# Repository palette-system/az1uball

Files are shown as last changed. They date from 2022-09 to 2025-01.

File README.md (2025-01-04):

# AZ1UBALL (1Uサイズのトラックボールモジュール)

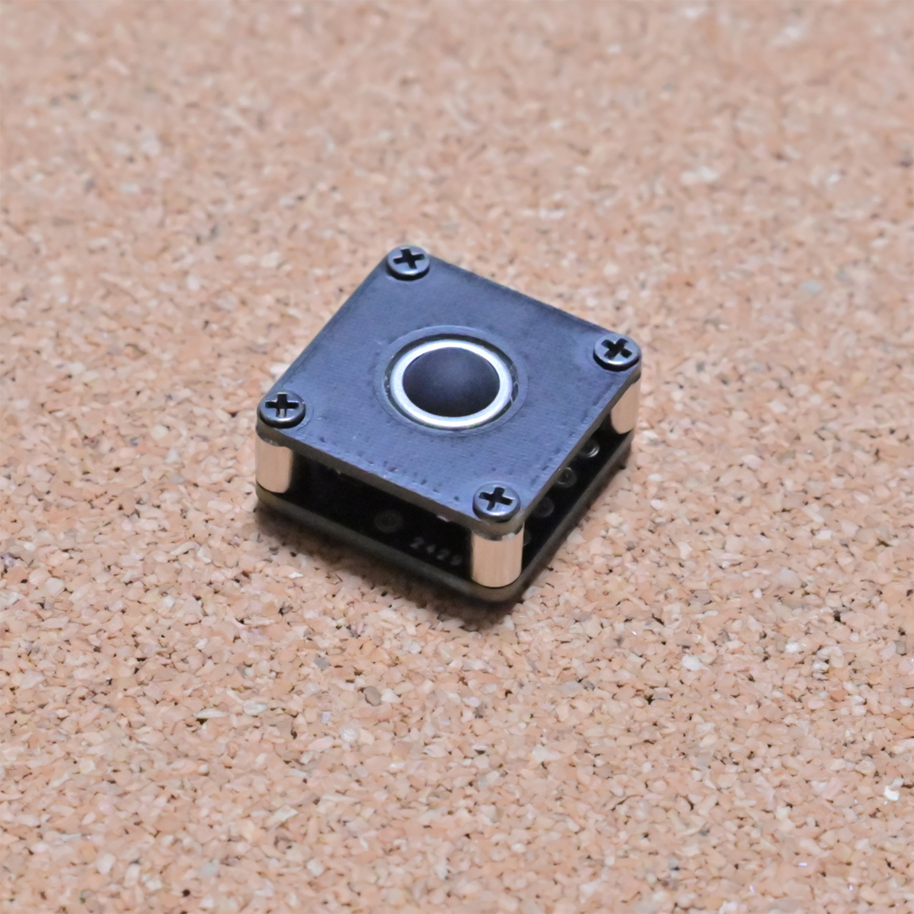
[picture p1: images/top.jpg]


<br><br>

## 商品ページ

https://booth.pm/ja/items/4202085

<br><br>

## 組み立て方

<br>
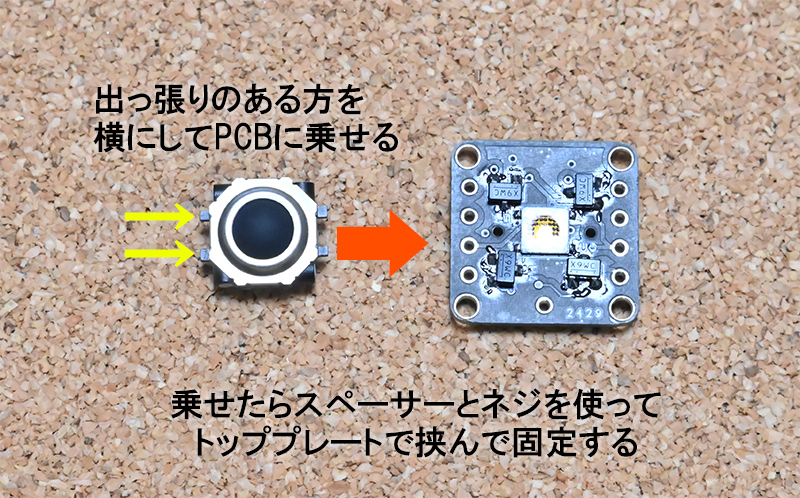
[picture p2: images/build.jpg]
<br>

<br><br>

## 接続方法（ProMicro、Raspberry Pi Pico）

VCC、GND、SDA、SCLの接続と、SDA、SCLにプルアップ抵抗が必要です。<br>
キーボード側に実装してある必要があります。<br>
<br>
※ 2023/5/23 以降のロットではプルアップ抵抗は必要ありません。<br>
※ 抵抗は 10kΩ ～ 2kΩ 程度<br>
<br>
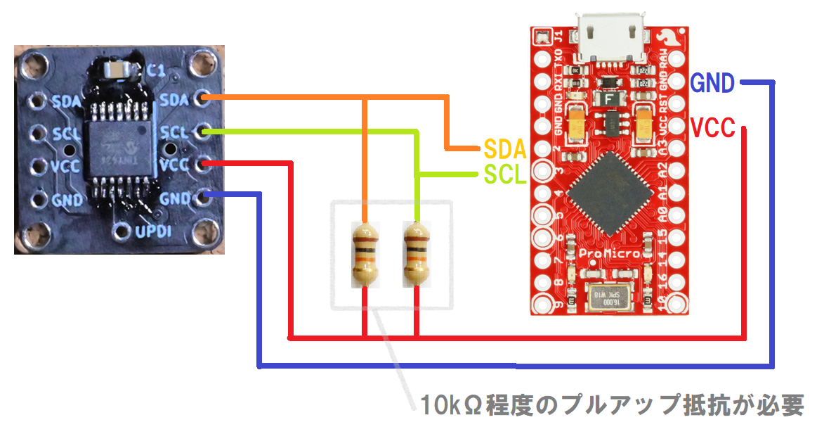
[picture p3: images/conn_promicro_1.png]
<br>

<br><br>
キーボード側にプルアップ抵抗が実装されていない場合は接続しない側のピンに抵抗を実装して下さい。
<br>
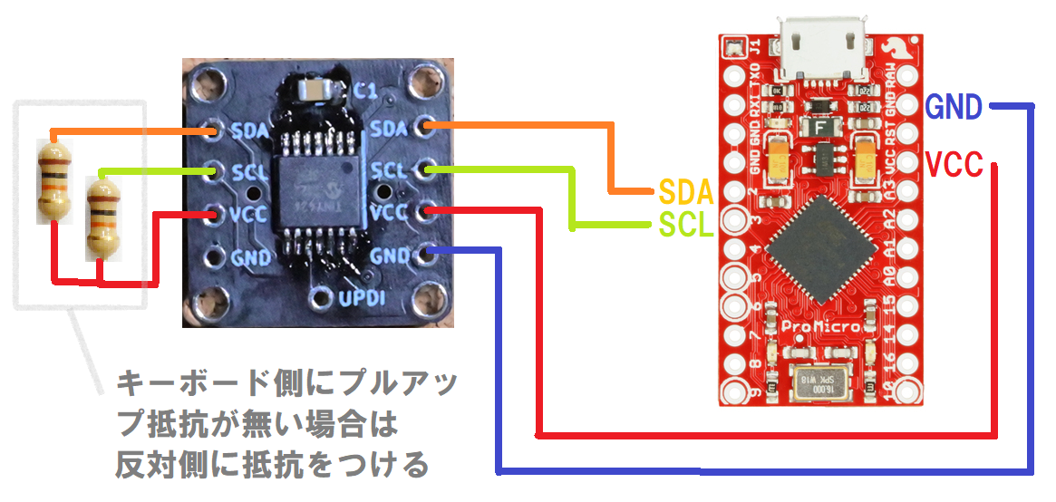
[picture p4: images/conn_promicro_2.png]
<br>

<br><br>

## 設定方法（QMK）
<br>
PIM447と同じ方法で使えるようになります。<br>
ブログがあるのでこの辺りを参考にして頂けたらです。<br>

<br><br>

takashicompany 様（PIM447）<br>
https://zenn.dev/takashicompany/articles/aed80d4eaff308

<br><br>

@74thの制作ログ 様（CircuitPython）（AZ1UBALL）<br>
https://74th.hateblo.jp/entry/2022/10/09/181609

<br><br>

taka8aru 様（AZ1UBALL）<br>
https://taka8aru.blogspot.com/2023/07/az1uballpro-microqmk-firmware-34.html

<br><br>

Yuta Sakai 様（AZ1UBALL）<br>
https://qiita.com/unbosoms/items/e58f12502115bfb7c303

<br><br>

metaphor 様（AZ1UBALL）<br>
デフォルト：大画面でもストレスのないカーソル移動<br>
レイヤー１：スクロールモード<br>
レイヤー３：細かいカーソル移動<br>
https://github.com/hayashiroto/zettelkasten-keyboard/blob/main/te96/rev1/keymaps/via_az1u/keymap.c

<br><br>

## 接続方法（AZ-CORE、えむごっち）

TRRSのジャックから直接接続できます<br>
<br>
※ プルアップ抵抗は必要ありません。<br>
　　　（ケーブルが長くて反応しない場合は2kΩ程度の抵抗でプルアップして下さい）<br><br>

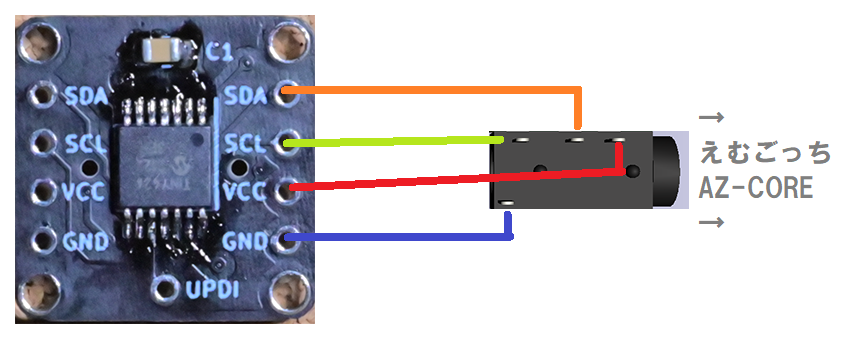
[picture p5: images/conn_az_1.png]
<br>

<br><br>
panda_micro越しに接続する事も出来ます。<br>
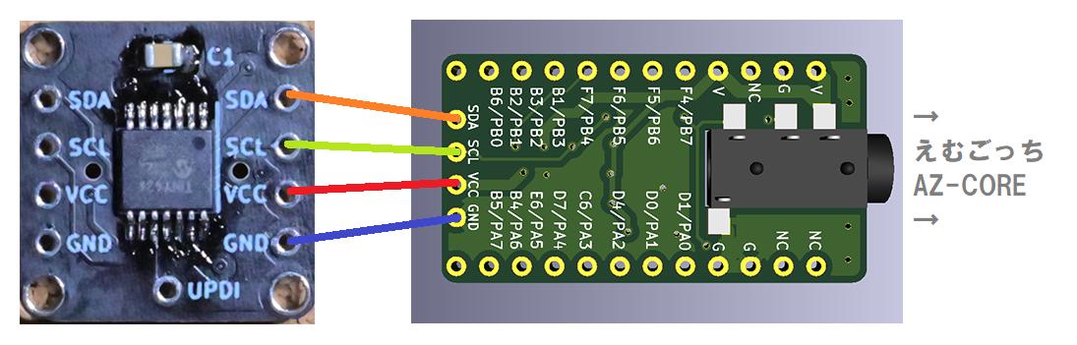
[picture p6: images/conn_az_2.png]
<br>

<br><br>

## 設定方法（AZ-CORE、えむごっち）
<br>
AZTOOLのI2C設定から追加するだけで使用できます。<br>
<br>
https://twitter.com/4py1/status/1568249131805835266

<br><br>

## 寸法
<br>
トッププレート<br>
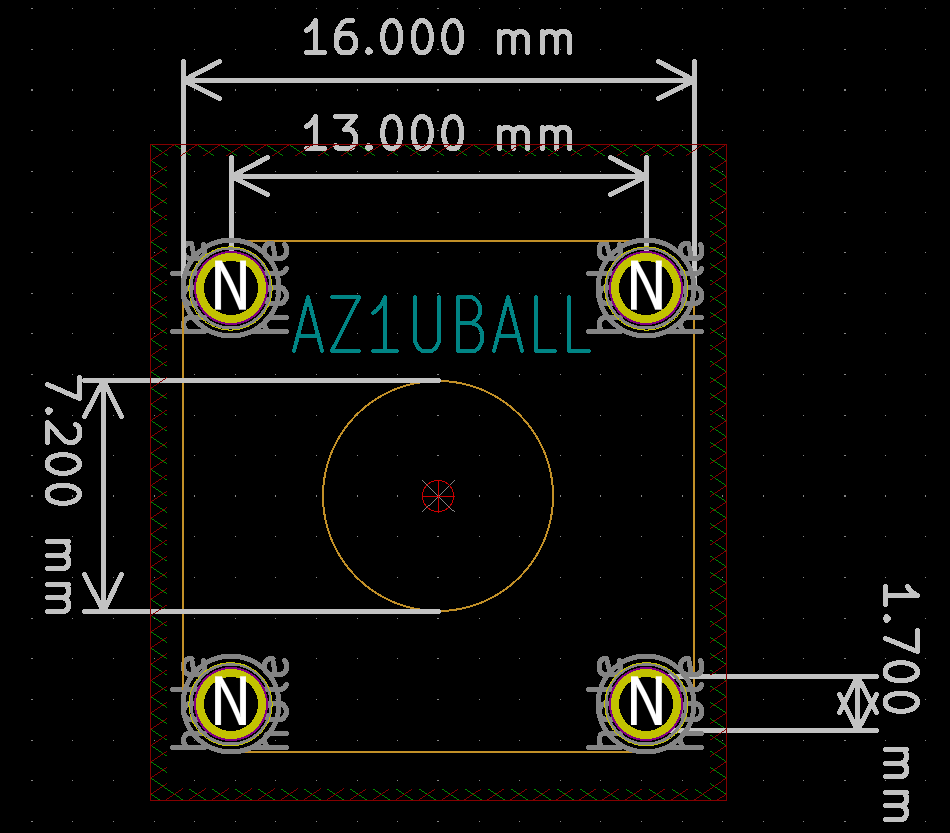
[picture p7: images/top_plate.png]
<br>
<a href="/hardware/plate_top/">トッププレート KiCadデータ</a>

<br><br>

断面<br>
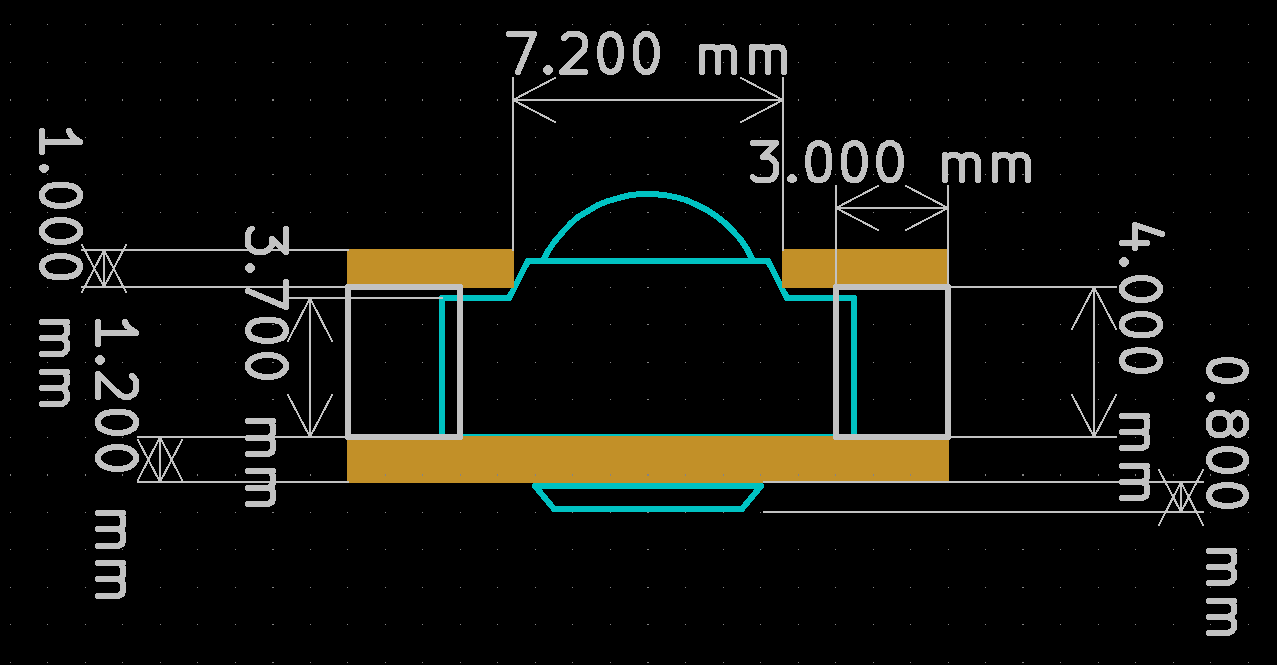
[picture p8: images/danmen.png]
<br>

<br><br>

## フットプリント
<br>

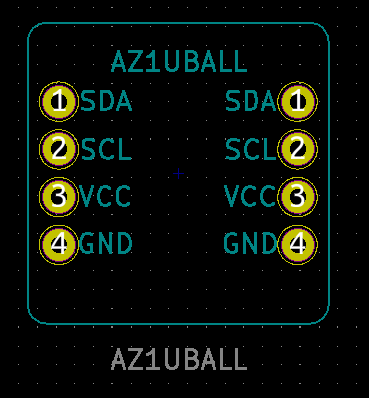
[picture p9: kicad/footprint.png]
<br>
<a href="/kicad/">AZ1UBALL.kicad_mod</a>
<br><br>

## ファームウェアの開発環境の作り方
<br>
１．このサイトの手順で書込み機や、ArduinoIDEのインストールを行う<br>
https://ameblo.jp/pta55/entry-12654450554.html
<br>
<br>
２．tiny424_trackball.inoをArduinoIDEで開く。<br>
<a href="/firmware/tiny424_trackball/tiny424_trackball.ino">tiny424_trackball.ino</a>
<br>
<br>
３．ボード設定を開き Chip を ATiny424 にして、Clock を 10MHz internal にして、書込みを実行する。<br>
　　(ボード設定のその他の項目はデフォルトのままでOKです)<br><br>
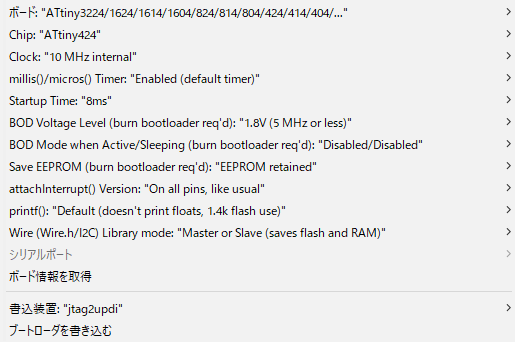
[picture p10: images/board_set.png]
<br>
<br>
<br>

## その他情報
<br>
動作電圧：　3.3V or 5V （どちらでも動作します）<br>
消費電力：　約 8mA<br>
I2Cアドレス：　0x0A<br>

<br><br>

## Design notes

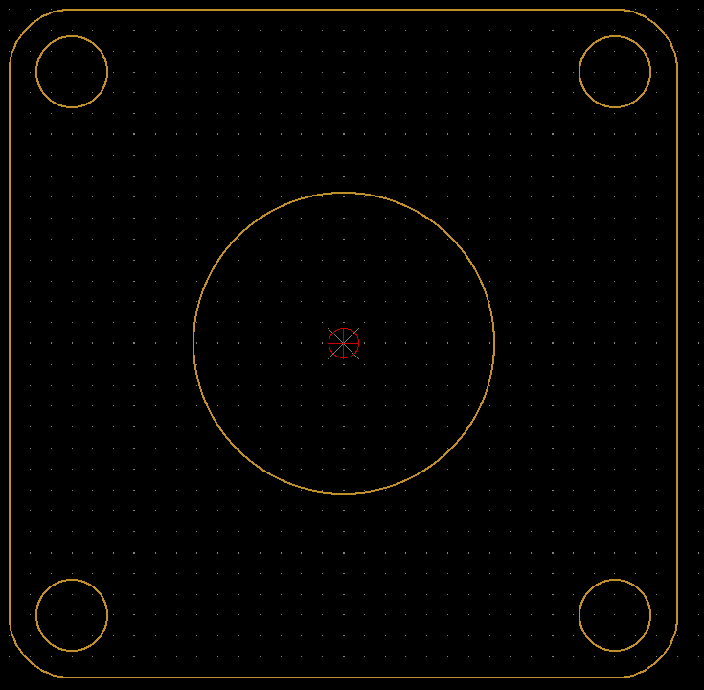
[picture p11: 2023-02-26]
hardware/plate_top/plate_top.png

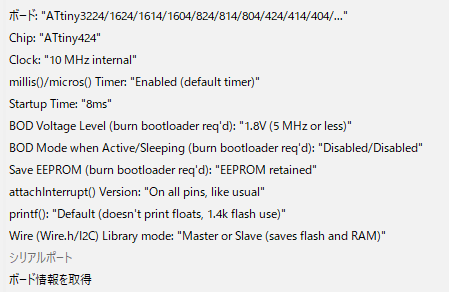
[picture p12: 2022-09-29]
images/board.png

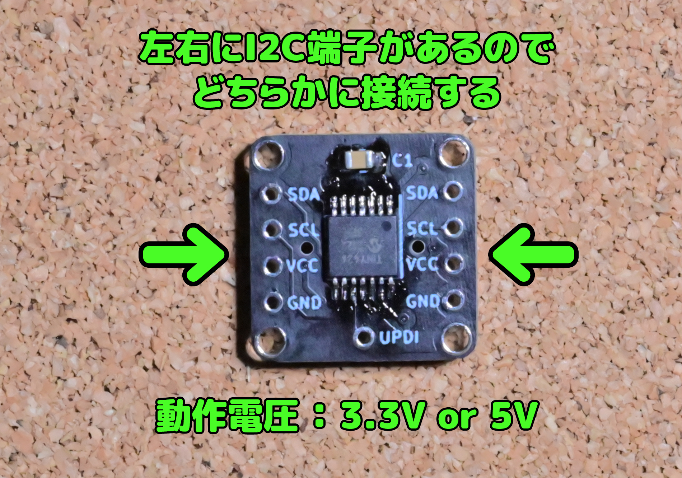
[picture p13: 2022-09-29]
images/conn.jpg

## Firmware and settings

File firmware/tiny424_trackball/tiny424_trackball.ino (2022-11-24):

// 1Uトラックボールユニットのホイールセンサーの入力をI2Cに流す

// 開発環境の作り方
// https://ameblo.jp/pta55/entry-12654450554.html

#include <Wire.h>
#include <avr/pgmspace.h>

// ATTiny202 本体のアドレス
#define I2C_SLAVE_ADD 0x0A

// カウントの方式(0=通常 / 1=AZ用)
uint8_t count_type = 0;

// 送信バッファ
uint8_t send_input[5];

// 最後にホールセンサからデータを受け取ったミリ秒
unsigned long last_time[4];

// I2Cイベント
void receiveEvent(int data_len); // データを受け取った
void requestEvent(); // データ要求を受け取った

// ホールセンサー読み込み用割り込み関数
void attachLeft();
void attachRight();
void attachUp();
void attachDown();

void setup() {
    // ロータリーエンコーダ読み込みピンの初期化
    pinMode(A4, INPUT); // 左
    pinMode(A1, INPUT); // 右
    pinMode(A5, INPUT); // 上
    pinMode(A3, INPUT); // 下
    pinMode(A6, INPUT_PULLUP);

    // バッファの初期化
    memset(send_input, 0x00, 5);
    memset(last_time, 0x00, 4 * sizeof(unsigned long));

    // I2C スレーブ初期化
    Wire.begin(I2C_SLAVE_ADD);
    Wire.onReceive(receiveEvent);
    Wire.onRequest(requestEvent);

    // ホールセンサーの回転健知時のイベント登録
    attachInterrupt(A4, attachLeft, CHANGE);
    attachInterrupt(A1, attachRight, CHANGE);
    attachInterrupt(A5, attachUp, CHANGE);
    attachInterrupt(A3, attachDown, CHANGE);
}

// コマンドを受け取った
void receiveEvent(int data_len) {
  // 最初の1バイトだけ取得
  uint8_t d = Wire.read();
  if (d == 0x90) {
    count_type = 0;
  } else if (d == 0x91) {
    count_type = 1;
  }
  // 残りは空読み
  while (Wire.available()) {
    Wire.read();
  }
}

// I2Cデータ要求を受け取った時の処理
void requestEvent() {
  // トラックボール操作の情報を送る
  Wire.write(send_input, 5);
  // バッファをリセット
  memset(send_input, 0x00, 4);
}

// ホールセンサーの回転を検知した時のイベント 0=左 / 1=右 / 2=上 / 3=下
void attachExec(int i) {
  unsigned long n = millis(); // 現在の時間
  unsigned long t = (n - last_time[i]); // 前回実行時からどれくらい時間が経ったか
  last_time[i] = n; // 最後に実行した時間を更新
  if (send_input[i] > 250) return; // 250超えをMAX値とする
  if (count_type == 0) {
    // 通常モードは常に１ずつ移動
    if (t > 1) {
      send_input[i] += 1;
    }
  } else if (count_type == 1) {
    // 経過時間別に移動距離加算
    if (t > 50) {
      send_input[i] += 1;
    } else if (t > 30) {
      send_input[i] += 2;
    } else if (t > 1) {
      send_input[i] += 3;
    }
  }
}

// 左ホイール回転検知
void attachLeft() {
  attachExec(0);
}

// 右ホイール回転検知
void attachRight() {
  attachExec(1);
}

// 上ホイール回転検知
void attachUp() {
  attachExec(2);
}

// 下ホイール回転検知
void attachDown() {
  attachExec(3);
}

void loop() {
  // タクトスイッチの状態を送信バッファに反映
  if (!digitalRead(A6)) {
    send_input[4] = 0x80;
  } else {
    send_input[4] = 0x00;
  }
  delay(2);
}

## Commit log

2022-11-11 add boardimg
2023-02-26 add top_plate
    [plate_top.kicad_pcb]
2023-02-26 update kicad 7
    [plate_top.kicad_pcb]
2023-02-26 Revert "update kicad 7"
    This reverts commit 5275a3c603f42084073b311218bfcafc03e2b97c.
    [plate_top.kicad_pcb]
2023-08-07 add footprint
